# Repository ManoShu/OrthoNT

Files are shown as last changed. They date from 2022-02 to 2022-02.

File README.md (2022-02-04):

# OrthoNT

An open-source, QMK-compatible, (loosely) ABNT2-based 6x14 ortholinear keyboard.

---

Layout:

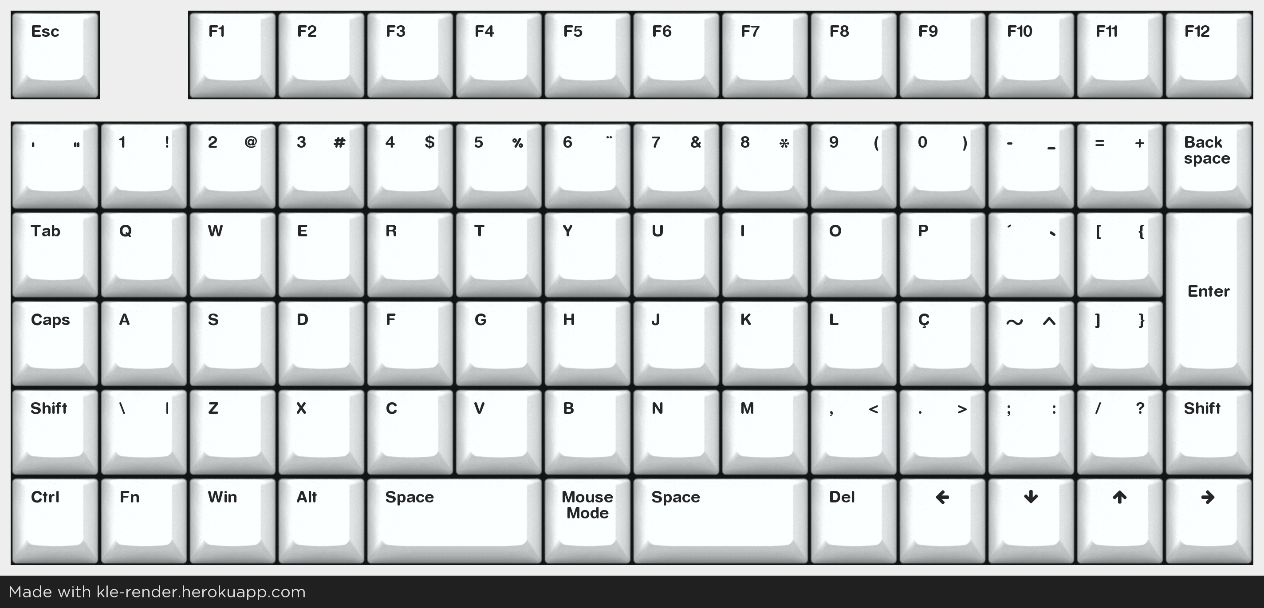
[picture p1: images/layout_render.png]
Keyboard Layout


Links: [KLE](http://www.keyboard-layout-editor.com/#/gists/c8b4991d1be04ef7142aadfa52a7956e), [JSON](https://gist.github.com/ManoShu/c8b4991d1be04ef7142aadfa52a7956e), [QMK](https://github.com/ManoShu/OrthoNT/tree/main/qmk/keyboards/handwired/orthont)

---

## PCB & Plate
The gerber files are under `production`. They had been used and confirmed to work, however use them at your own risk.

## QMK

No plan to integrate to the main QMK repository yet, as I am waiting for a proper VID/PID allocation. The files are on the `qmk` directory; just copy folder to qmk and it should work (HOWEVER the files have been confirmed working on QMK 0.2.2 [check yours with `qmk --version`], previous versions might not have support for some of the tags in the` info.json` file).

## VIA / VIAL

**NOTE: VIA / VIAL files have not been uploaded yet**

A `via` keymap is available allowing to use VIA to change keybindings withou the need to setup QMK. 
It is not integrated with the official repository yet (as I am waiting for a proper VID allocation), but the .json file required to change bindings is available on the `via` directory.

A VIAL-compatible keymap is also available. Drop the keyboard folder to your `vial-qmk` directory and it should also work right off the bat.

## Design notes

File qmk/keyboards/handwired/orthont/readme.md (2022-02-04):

# orthont

orthont

*A short description of the keyboard/project*

* Keyboard Maintainer: [ManoShu](https://github.com/yourusername)
* Hardware Supported: *The PCBs, controllers supported*
* Hardware Availability: *Links to where you can find this hardware*

Make example for this keyboard (after setting up your build environment):

    make orthont:default

Flashing example for this keyboard:

    make orthont:default:flash

See the [build environment setup](https://docs.qmk.fm/#/getting_started_build_tools) and the [make instructions](https://docs.qmk.fm/#/getting_started_make_guide) for more information. Brand new to QMK? Start with our [Complete Newbs Guide](https://docs.qmk.fm/#/newbs).

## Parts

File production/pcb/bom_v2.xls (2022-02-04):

Comment | Designator | Footprint | LCSC Part
0805W8F4700T5E | R7 | R_0805_2012Metric_Pad1.15x1.40mm_HandSolder | C17710
CC0805KRX7R9BB104 | C4,C5,C6 | C_0805_2012Metric_Pad1.15x1.40mm_HandSolder | C49678
0805W8F1000T5E | R8 | R_0805_2012Metric_Pad1.15x1.40mm_HandSolder | C17408
ATMEGA32U4-AU | U1 | TQFP-44_10x10mm_P0.8mm | C44854
USBLC6-2SC6 | U2 | SOT-23-6_Handsoldering | C2687116
1N4148W | D_R3C13,D_R5C13,D_R5C12,D_R5C11,D_R5C10,D_R5C9,D_R5C8,D_R5C6,D_R5C4,D_R5C3,D_R5C2,D_R5C1,D_R5C0,D_R4C13,D_R4C12,D_R4C11,D_R4C10,D_R4C9,D_R4C8,D_R4C7,D_R4C6,D_R4C5,D_R4C4,D_R4C3,D_R4C2,D_R4C1,D_R4C0,D_R3C12,D_R3C11,D_R3C10,D_R3C9,D_R3C8,D_R3C7,D_R3C6,D_R3C5,D_R3C4,D_R3C3,D_R3C2,D_R3C1,D_R3C0,D_R2C13,D_R2C12,D_R2C11,D_R2C10,D_R2C9,D_R2C8,D_R2C7,D_R2C6,D_R2C5,D_R2C4,D_R2C3,D_R2C2,D_R2C1,D_R2C0,D_R1C13,D_R1C12,D_R1C11,D_R1C10,D_R1C9,D_R1C8,D_R1C7,D_R1C6,D_R1C5,D_R1C4,D_R1C3,D_R1C2,D_R1C1,D_R1C0,D_R0C13,D_R0C12,D_R0C11,D_R0C10,D_R0C9,D_R0C8,D_R0C7,D_R0C6,D_R0C5,D_R0C4,D_R0C3,D_R0C2,D_R0C0 | D_SOD123_hand | C81598
0805W8F5101T5E | R6,R5 | R_0805_2012Metric_Pad1.15x1.40mm_HandSolder | C27834
CL21B105KBFNNNE | C8 | C_0805_2012Metric_Pad1.15x1.40mm_HandSolder | C28323
0805W8F1002T5E | R9,R1,R2 | R_0805_2012Metric_Pad1.15x1.40mm_HandSolder | C17414
TYPE-C-31-M-12 | USB1 | HRO-TYPE-C-31-M-12-HandSoldering | C165948
CL21A106KAYNNNE | C7 | C_0805_2012Metric_Pad1.15x1.40mm_HandSolder | C15850
TS-1187A-B-A-B | SW1 | SW_SPST_SKQG_WithStem | C318884
JK-NSMD050-13.2V | F1 | Fuse_1206_3216Metric_Pad1.42x1.75mm_HandSolder | C369159
0805W8F220JT5E | R3,R4 | R_0805_2012Metric_Pad1.15x1.40mm_HandSolder | C17561
X322516MLB4SI | X1 | Crystal_SMD_3225-4Pin_3.2x2.5mm_HandSoldering | C13738
AO3401A | Q1 | SOT-23_Handsoldering | C15127
CL21C220JBANNNC | C1,C2 | C_0805_2012Metric_Pad1.15x1.40mm_HandSolder | C1804
0805W8F2001T5E | R_R4C7,R_R5C13,R_R5C12,R_R5C11,R_R5C10,R_R5C9,R_R5C8,R_R5C6,R_R5C4,R_R5C3,R_R5C2,R_R5C1,R_R5C0,R_R4C13,R_R4C12,R_R4C11,R_R4C10,R_R4C9,R_R4C8,R_R4C6,R_R4C5,R_R4C4,R_R4C3,R_R4C2,R_R4C1,R_R4C0,R_R3C12,R_R3C11,R_R3C10,R_R3C9,R_R3C8,R_R3C7,R_R3C6,R_R3C5,R_R3C4,R_R3C3,R_R3C2,R_R3C1,R_R3C0,R_R2C13,R_R2C12,R_R2C11,R_R2C10,R_R2C9,R_R2C8,R_R2C7,R_R2C6,R_R2C5,R_R2C4,R_R2C3,R_R2C2,R_R2C1,R_R2C0,R_R1C13,R_R1C12,R_R1C11,R_R1C10,R_R1C9,R_R1C8,R_R1C7,R_R1C6,R_R1C5,R_R1C4,R_R1C3,R_R1C2,R_R1C1,R_R1C0,R_R0C13,R_R0C12,R_R0C11,R_R0C10,R_R0C9,R_R0C8,R_R0C7,R_R0C6,R_R0C5,R_R0C4,R_R0C3,R_R0C2,R_R0C0 | R_0805_2012Metric_Pad1.15x1.40mm_HandSolder | C17604
C2290 | D1 | LED_0603_1608Metric_Pad1.05x0.95mm_HandSolder | C2290
SM04B-SRSS-TB(LF)(SN) | J1 | JST_SH_SM04B-SRSS-TB_1x04-1MP_P1.00mm_Horizontal | C160404

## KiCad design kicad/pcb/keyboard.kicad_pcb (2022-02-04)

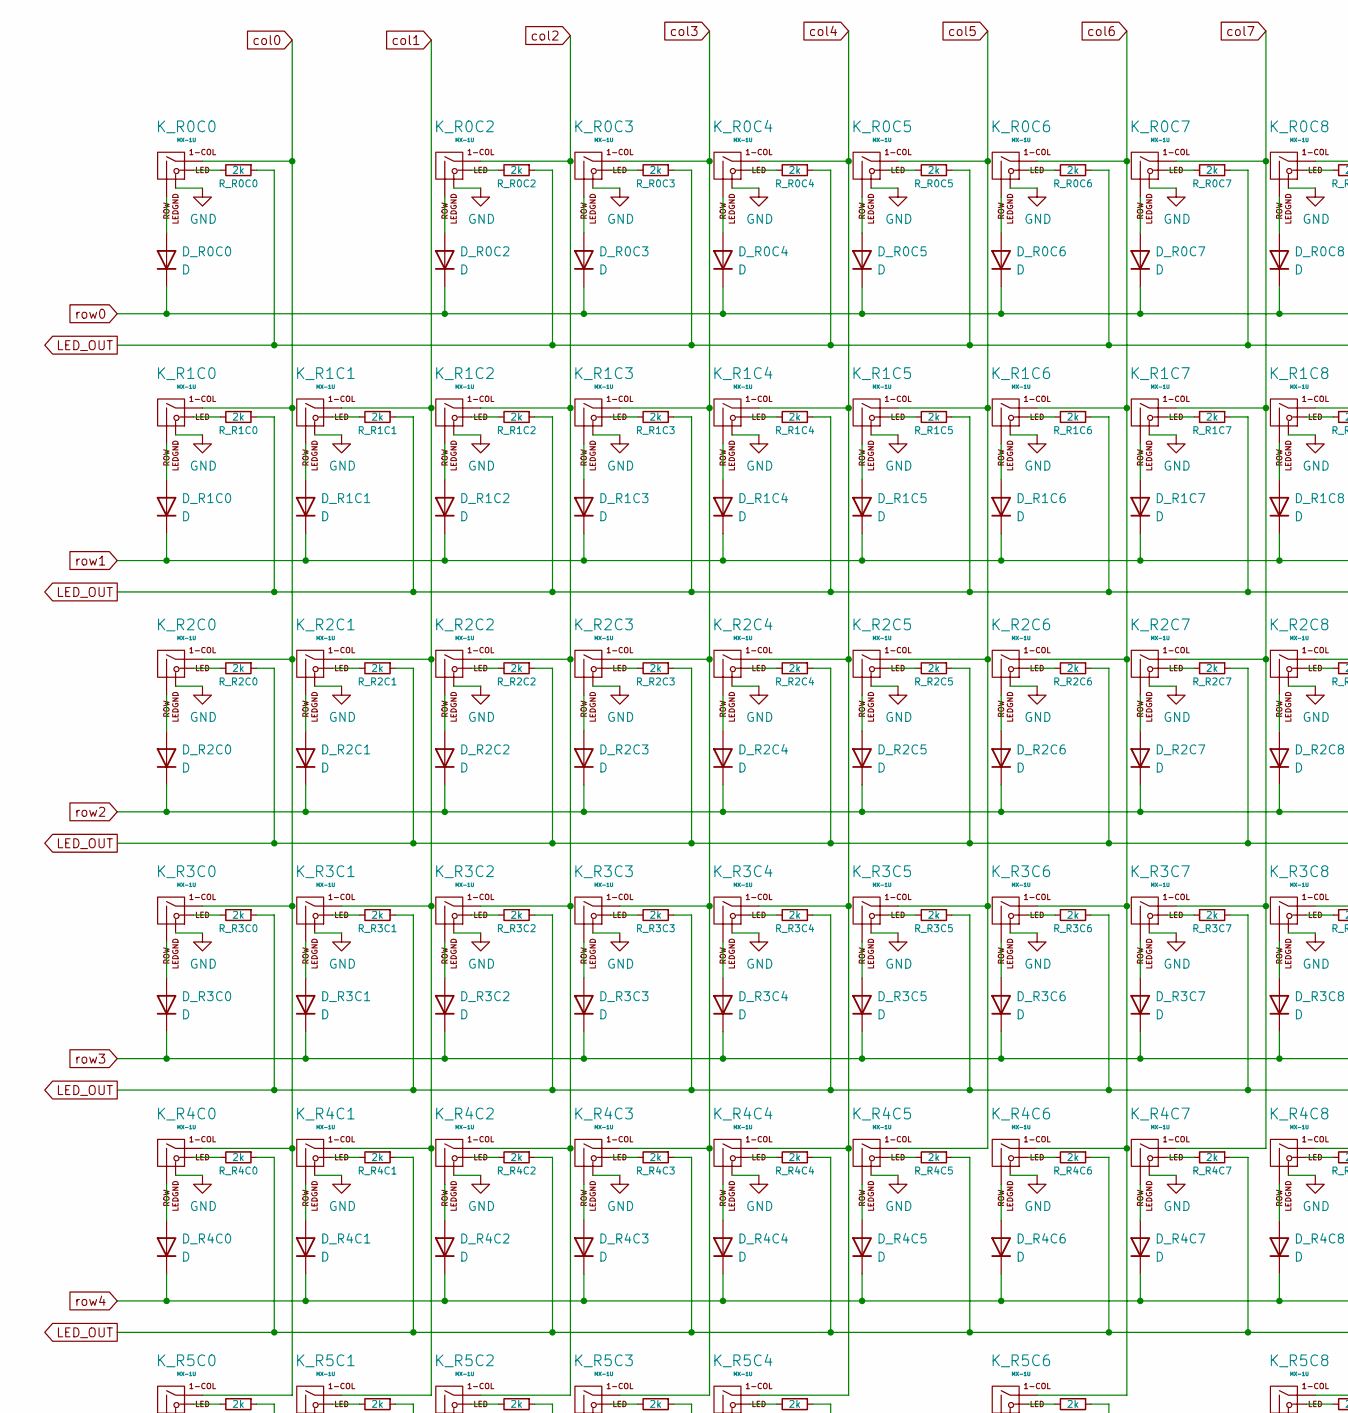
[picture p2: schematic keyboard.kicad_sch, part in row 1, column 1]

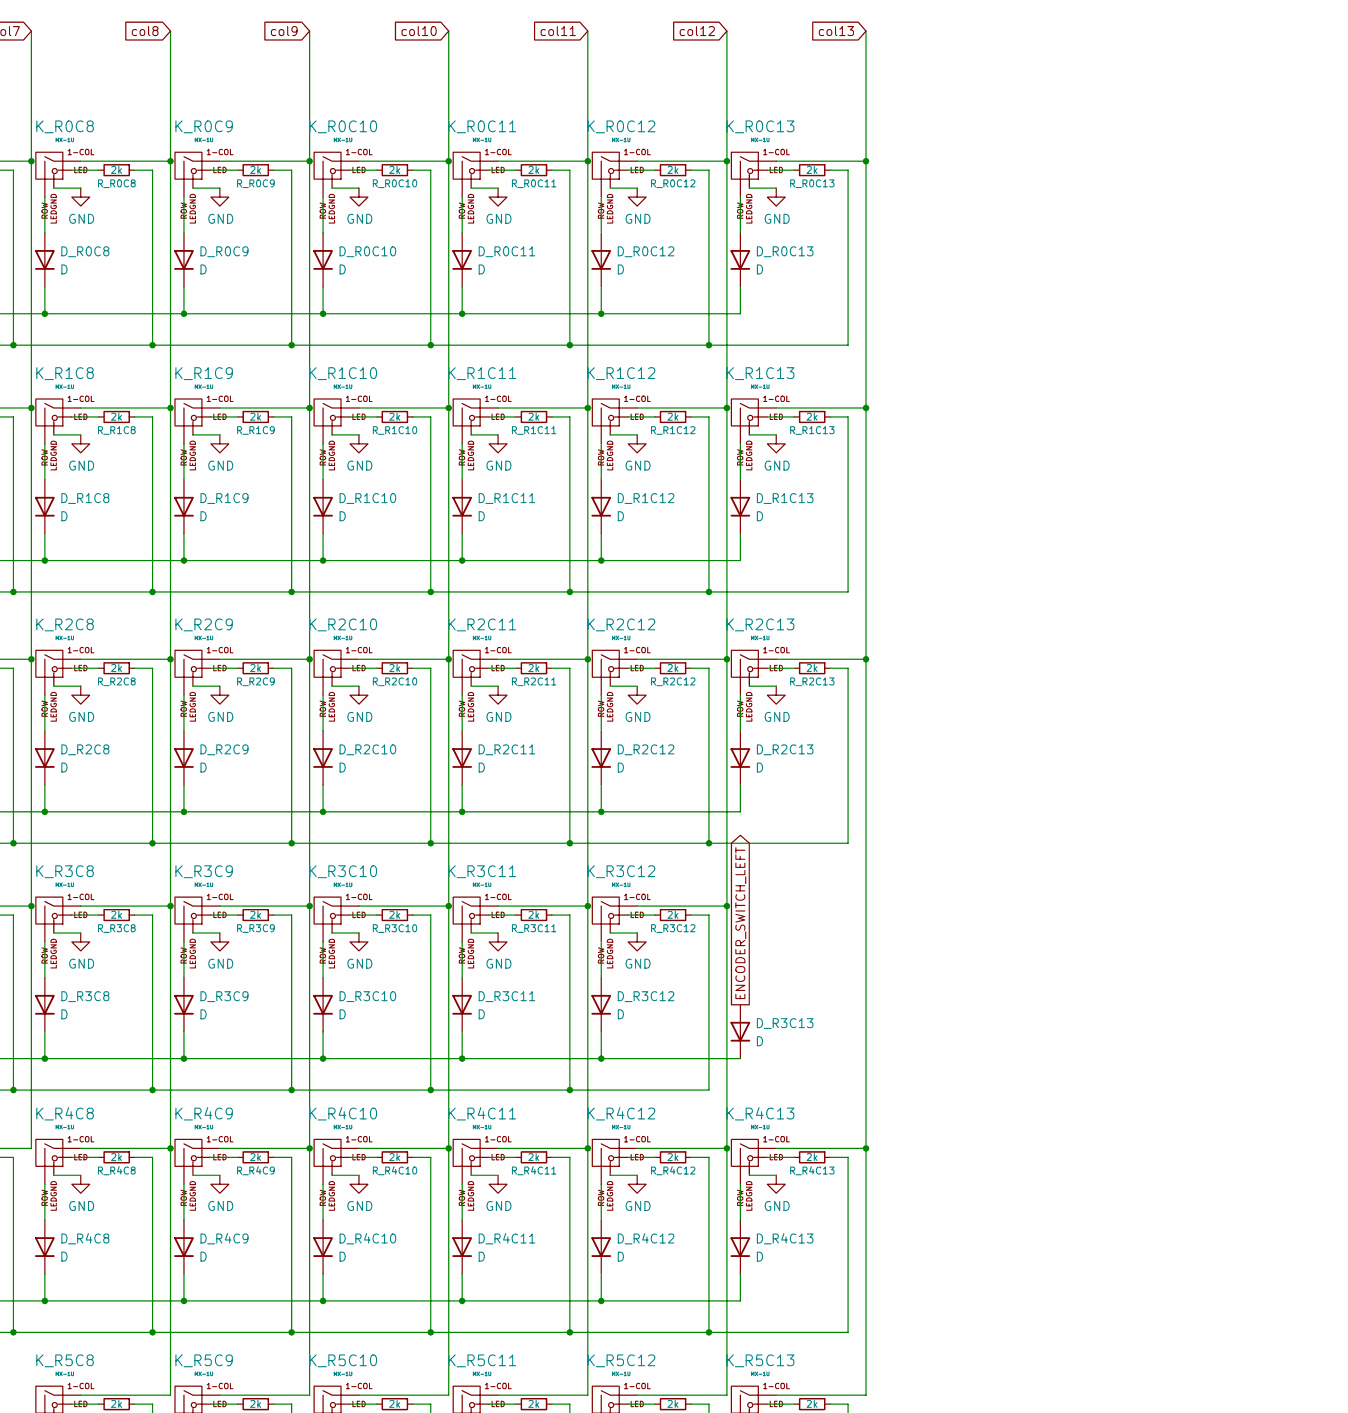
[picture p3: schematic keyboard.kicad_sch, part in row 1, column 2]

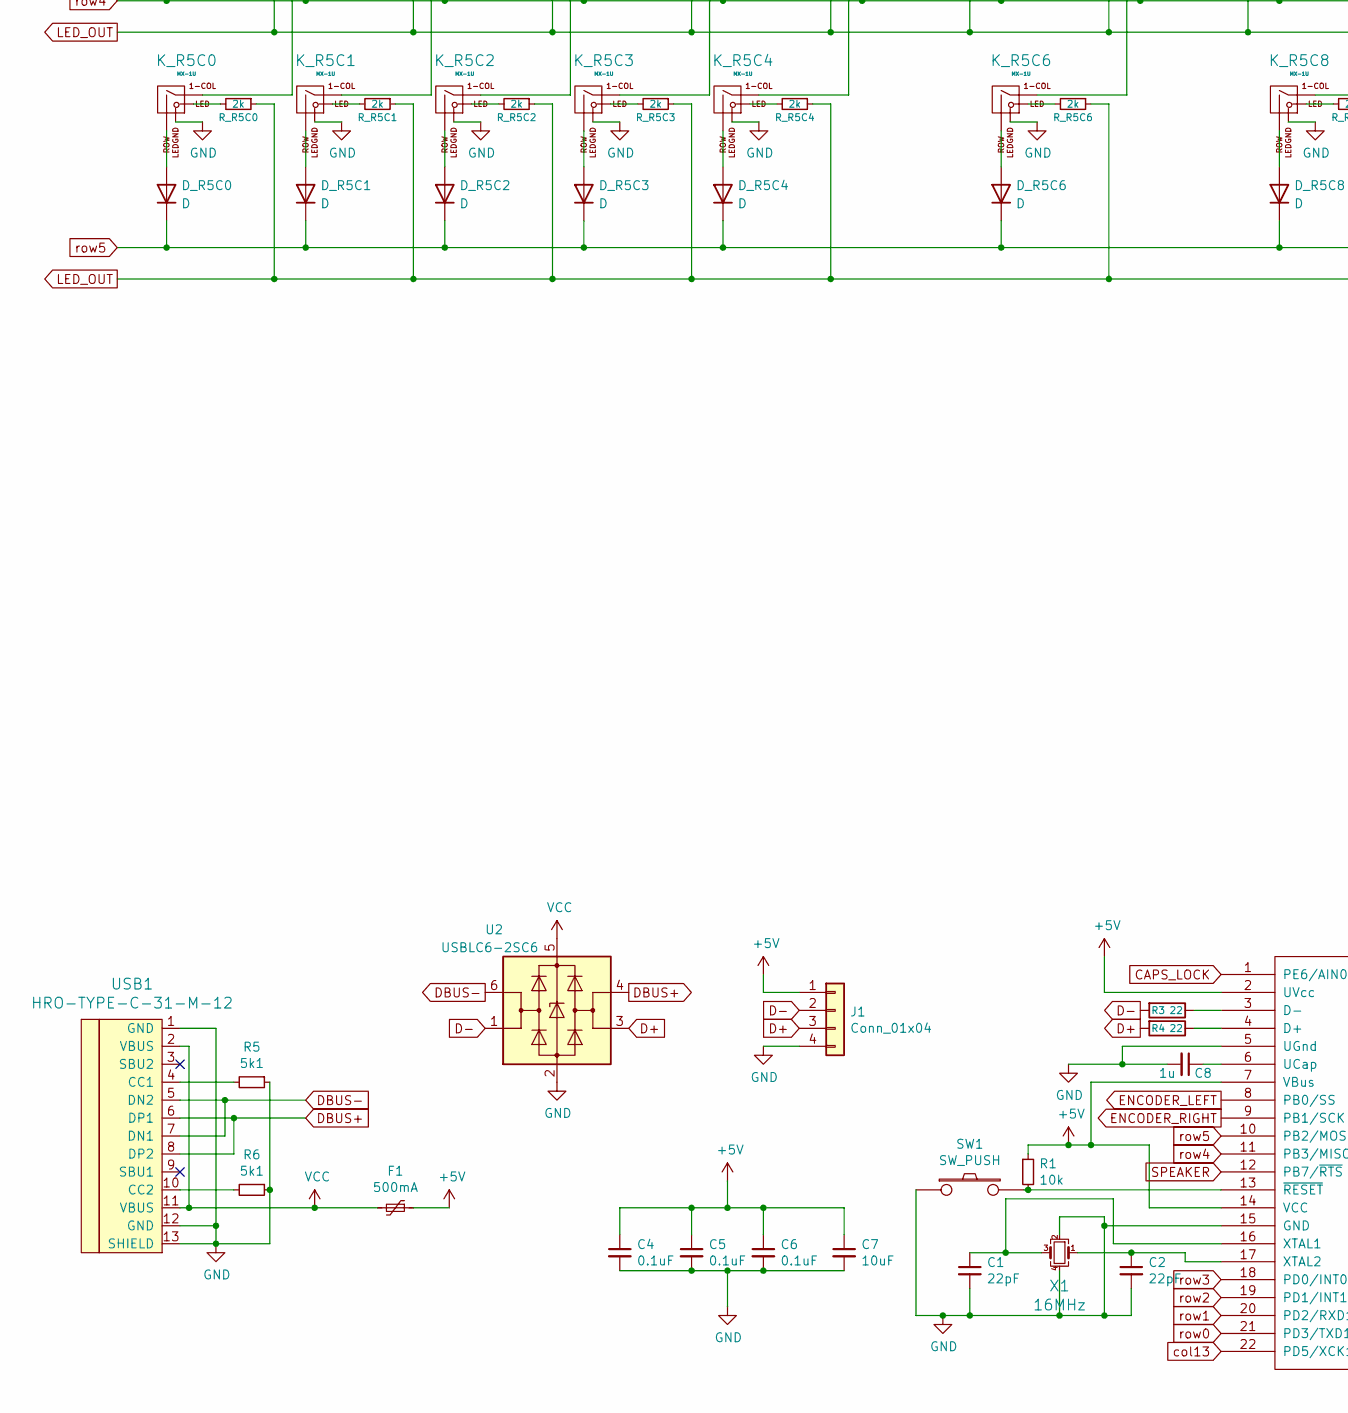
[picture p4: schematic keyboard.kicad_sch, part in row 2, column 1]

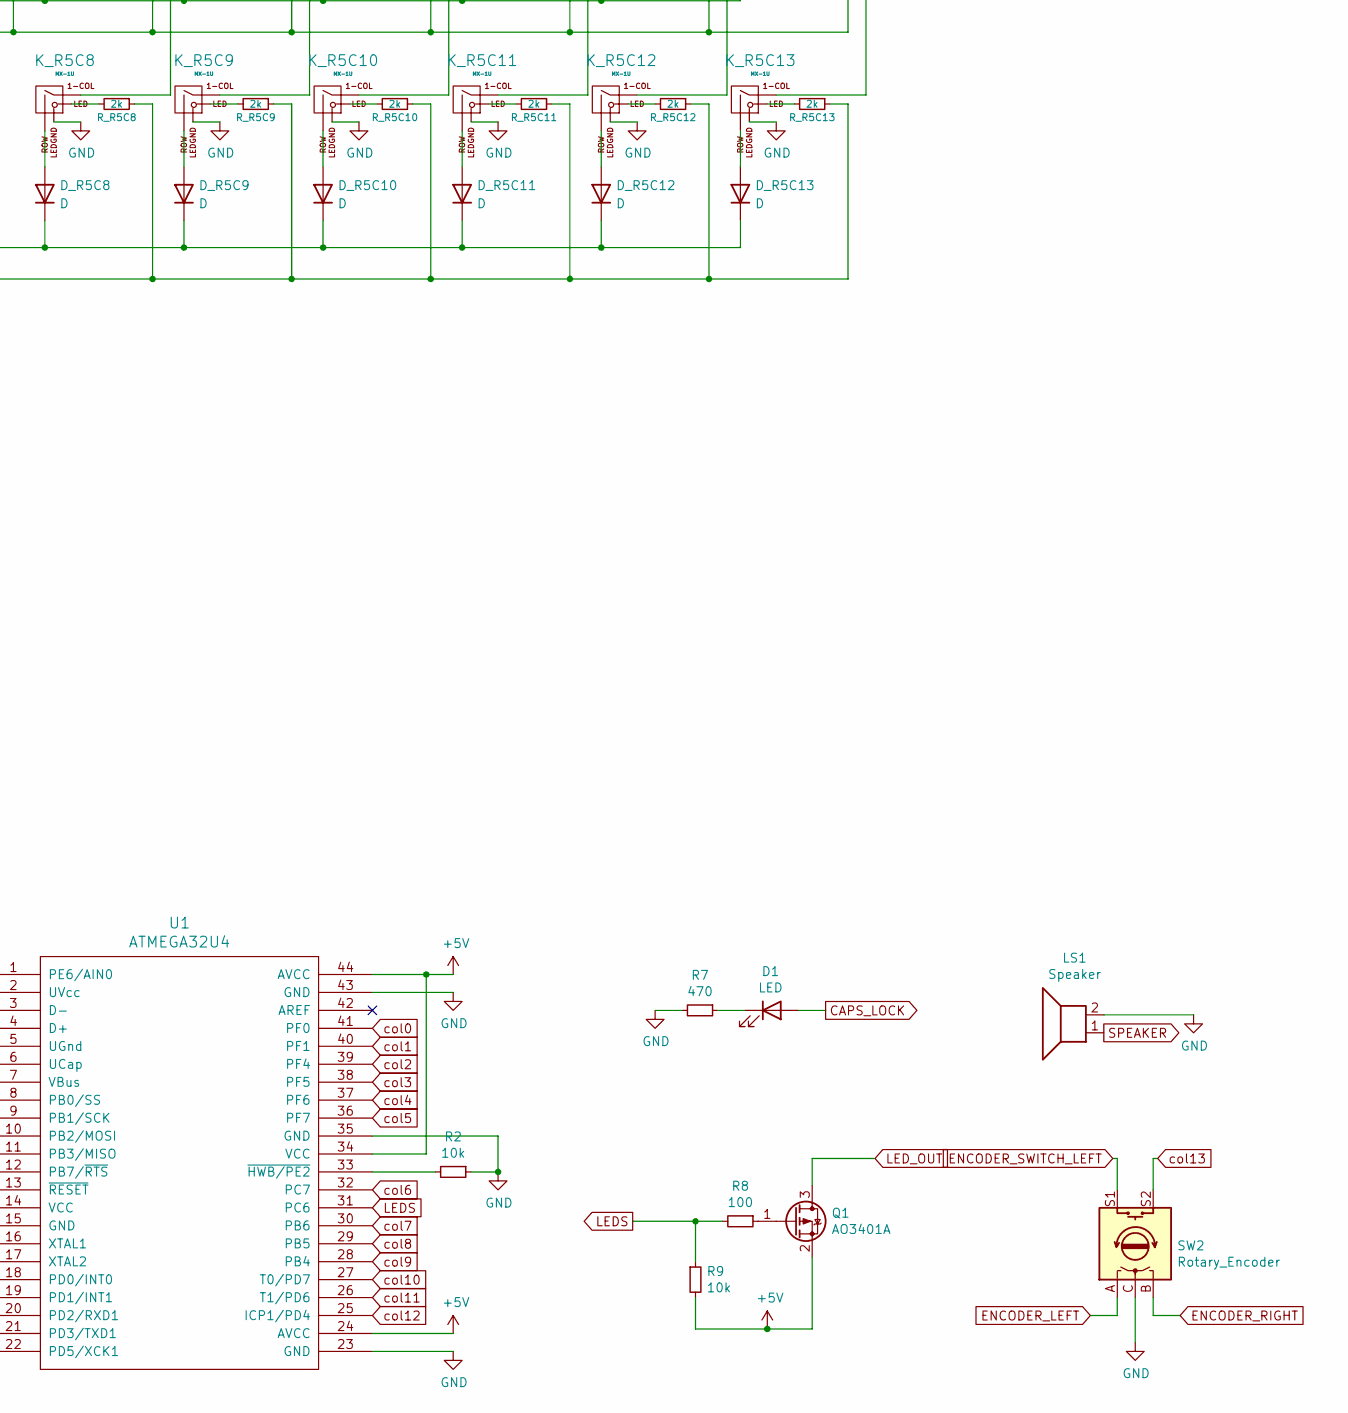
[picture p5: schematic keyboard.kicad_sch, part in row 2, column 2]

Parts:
C1, C2: 22pF; C_0805_2012Metric_Pad1.15x1.40mm_HandSolder
C4, C5, C6: 0.1uF; C_0805_2012Metric_Pad1.15x1.40mm_HandSolder
C7: 10uF; C_0805_2012Metric_Pad1.15x1.40mm_HandSolder
C8: 1u; C_0805_2012Metric_Pad1.15x1.40mm_HandSolder
D1: LED; LED_0603_1608Metric_Pad1.05x0.95mm_HandSolder
D_R0C0, D_R0C2, D_R0C3, D_R0C4, D_R0C5, D_R0C6, D_R0C7, D_R0C8, D_R0C9, D_R0C10, D_R0C11, D_R0C12, D_R0C13, D_R1C0, D_R1C1, D_R1C2, D_R1C3, D_R1C4, D_R1C5, D_R1C6, D_R1C7, D_R1C8, D_R1C9, D_R1C10, D_R1C11, D_R1C12, D_R1C13, D_R2C0, D_R2C1, D_R2C2, D_R2C3, D_R2C4, D_R2C5, D_R2C6, D_R2C7, D_R2C8, D_R2C9, D_R2C10, D_R2C11, D_R2C12, D_R2C13, D_R3C0, D_R3C1, D_R3C2, D_R3C3, D_R3C4, D_R3C5, D_R3C6, D_R3C7, D_R3C8, D_R3C9, D_R3C10, D_R3C11, D_R3C12, D_R3C13, D_R4C0, D_R4C1, D_R4C2, D_R4C3, D_R4C4, D_R4C5, D_R4C6, D_R4C7, D_R4C8, D_R4C9, D_R4C10, D_R4C11, D_R4C12, D_R4C13, D_R5C0, D_R5C1, D_R5C2, D_R5C3, D_R5C4, D_R5C6, D_R5C8, D_R5C9, D_R5C10, D_R5C11, D_R5C12, D_R5C13: D; D_SOD123_hand
F1: 500mA; Fuse_1206_3216Metric_Pad1.42x1.75mm_HandSolder
J1: Conn_01x04; JST_SH_SM04B-SRSS-TB_1x04-1MP_P1.00mm_Horizontal
K_R0C0, K_R0C2, K_R0C3, K_R0C4, K_R0C5, K_R0C6, K_R0C7, K_R0C8, K_R0C9, K_R0C10, K_R0C11, K_R0C12, K_R0C13, K_R1C0, K_R1C1, K_R1C2, K_R1C3, K_R1C4, K_R1C5, K_R1C6, K_R1C7, K_R1C8, K_R1C9, K_R1C10, K_R1C11, K_R1C12, K_R1C13, K_R2C0, K_R2C1, K_R2C2, K_R2C3, K_R2C4, K_R2C5, K_R2C6, K_R2C7, K_R2C8, K_R2C9, K_R2C10, K_R2C11, K_R2C12, K_R3C0, K_R3C1, K_R3C2, K_R3C3, K_R3C4, K_R3C5, K_R3C6, K_R3C7, K_R3C8, K_R3C9, K_R3C10, K_R3C11, K_R3C12, K_R4C0, K_R4C1, K_R4C2, K_R4C3, K_R4C4, K_R4C5, K_R4C6, K_R4C7, K_R4C8, K_R4C9, K_R4C10, K_R4C11, K_R4C12, K_R4C13, K_R5C0, K_R5C1, K_R5C2, K_R5C3, K_R5C6, K_R5C9, K_R5C10, K_R5C11, K_R5C12, K_R5C13: MX-1U; MXOnly-1U
K_R2C13: MX-1U; MXOnly-2U_RightAngle
K_R5C4, K_R5C8: MX-1U; MXOnly-2U
LS1: Speaker; PinHeader_1x02_P2.54mm_Horizontal
Q1: AO3401A; SOT-23_Handsoldering
R1, R2, R9: 10k; R_0805_2012Metric_Pad1.15x1.40mm_HandSolder
R3, R4: 22; R_0805_2012Metric_Pad1.15x1.40mm_HandSolder
R5, R6: 5k1; R_0805_2012Metric_Pad1.15x1.40mm_HandSolder
R7: 470; R_0805_2012Metric_Pad1.15x1.40mm_HandSolder
R8: 100; R_0805_2012Metric_Pad1.15x1.40mm_HandSolder
R_R0C0, R_R0C2, R_R0C3, R_R0C4, R_R0C5, R_R0C6, R_R0C7, R_R0C8, R_R0C9, R_R0C10, R_R0C11, R_R0C12, R_R0C13, R_R1C0, R_R1C1, R_R1C2, R_R1C3, R_R1C4, R_R1C5, R_R1C6, R_R1C7, R_R1C8, R_R1C9, R_R1C10, R_R1C11, R_R1C12, R_R1C13, R_R2C0, R_R2C1, R_R2C2, R_R2C3, R_R2C4, R_R2C5, R_R2C6, R_R2C7, R_R2C8, R_R2C9, R_R2C10, R_R2C11, R_R2C12, R_R2C13, R_R3C0, R_R3C1, R_R3C2, R_R3C3, R_R3C4, R_R3C5, R_R3C6, R_R3C7, R_R3C8, R_R3C9, R_R3C10, R_R3C11, R_R3C12, R_R4C0, R_R4C1, R_R4C2, R_R4C3, R_R4C4, R_R4C5, R_R4C6, R_R4C7, R_R4C8, R_R4C9, R_R4C10, R_R4C11, R_R4C12, R_R4C13, R_R5C0, R_R5C1, R_R5C2, R_R5C3, R_R5C4, R_R5C6, R_R5C8, R_R5C9, R_R5C10, R_R5C11, R_R5C12, R_R5C13: 2k; R_0805_2012Metric_Pad1.15x1.40mm_HandSolder
SW1: SW_PUSH; SW_SPST_SKQG_WithStem
SW2: Rotary_Encoder; RotaryEncoder_Alps_EC11E-Switch_Vertical_H20mm
U1: ATMEGA32U4; TQFP-44_10x10mm_P0.8mm
U2: USBLC6-2SC6; SOT-23-6_Handsoldering
USB1: HRO-TYPE-C-31-M-12; HRO-TYPE-C-31-M-12-HandSoldering
X1: 16MHz; Crystal_SMD_3225-4Pin_3.2x2.5mm_HandSoldering

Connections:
+5V: C4.1, C5.1, C6.1, C7.1, F1.1, J1.1, Q1.2 (S), R1.1, R9.2, U1.2 (UVcc), U1.7 (VBus), U1.14 (VCC), U1.24 (AVCC), U1.34 (VCC), U1.44 (AVCC)
CAPS_LOCK: D1.2 (A), U1.1 (PE6/AIN0)
D+: J1.3, R4.2, U2.3 (I/O2)
D-: J1.2, R3.2, U2.1 (I/O1)
DBUS+: U2.4 (I/O2), USB1.6 (DP1), USB1.8 (DP2)
DBUS-: U2.6 (I/O1), USB1.5 (DN2), USB1.7 (DN1)
ENCODER_LEFT: SW2.A, U1.8 (PB0/SS)
ENCODER_RIGHT: SW2.B, U1.9 (PB1/SCK)
ENCODER_SWITCH_LEFT: D_R3C13.2 (A), SW2.S1
GND: C1.2, C2.2, C4.2, C5.2, C6.2, C7.2, C8.2, J1.4, K_R0C0.4 (LEDGND), K_R0C2.4 (LEDGND), K_R0C3.4 (LEDGND), K_R0C4.4 (LEDGND), K_R0C5.4 (LEDGND), K_R0C6.4 (LEDGND), K_R0C7.4 (LEDGND), K_R0C8.4 (LEDGND), K_R0C9.4 (LEDGND), K_R0C10.4 (LEDGND), K_R0C11.4 (LEDGND), K_R0C12.4 (LEDGND), K_R0C13.4 (LEDGND), K_R1C0.4 (LEDGND), K_R1C1.4 (LEDGND), K_R1C2.4 (LEDGND), K_R1C3.4 (LEDGND), K_R1C4.4 (LEDGND), K_R1C5.4 (LEDGND), K_R1C6.4 (LEDGND), K_R1C7.4 (LEDGND), K_R1C8.4 (LEDGND), K_R1C9.4 (LEDGND), K_R1C10.4 (LEDGND), K_R1C11.4 (LEDGND), K_R1C12.4 (LEDGND), K_R1C13.4 (LEDGND), K_R2C0.4 (LEDGND), K_R2C1.4 (LEDGND), K_R2C2.4 (LEDGND), K_R2C3.4 (LEDGND), K_R2C4.4 (LEDGND), K_R2C5.4 (LEDGND), K_R2C6.4 (LEDGND), K_R2C7.4 (LEDGND), K_R2C8.4 (LEDGND), K_R2C9.4 (LEDGND), K_R2C10.4 (LEDGND), K_R2C11.4 (LEDGND), K_R2C12.4 (LEDGND), K_R2C13.4 (LEDGND), K_R3C0.4 (LEDGND), K_R3C1.4 (LEDGND), K_R3C2.4 (LEDGND), K_R3C3.4 (LEDGND), K_R3C4.4 (LEDGND), K_R3C5.4 (LEDGND), K_R3C6.4 (LEDGND), K_R3C7.4 (LEDGND), K_R3C8.4 (LEDGND), K_R3C9.4 (LEDGND), K_R3C10.4 (LEDGND), K_R3C11.4 (LEDGND), K_R3C12.4 (LEDGND), K_R4C0.4 (LEDGND), K_R4C1.4 (LEDGND), K_R4C2.4 (LEDGND), K_R4C3.4 (LEDGND), K_R4C4.4 (LEDGND), K_R4C5.4 (LEDGND), K_R4C6.4 (LEDGND), K_R4C7.4 (LEDGND), K_R4C8.4 (LEDGND), K_R4C9.4 (LEDGND), K_R4C10.4 (LEDGND), K_R4C11.4 (LEDGND), K_R4C12.4 (LEDGND), K_R4C13.4 (LEDGND), K_R5C0.4 (LEDGND), K_R5C1.4 (LEDGND), K_R5C2.4 (LEDGND), K_R5C3.4 (LEDGND), K_R5C4.4 (LEDGND), K_R5C6.4 (LEDGND), K_R5C8.4 (LEDGND), K_R5C9.4 (LEDGND), K_R5C10.4 (LEDGND), K_R5C11.4 (LEDGND), K_R5C12.4 (LEDGND), K_R5C13.4 (LEDGND), LS1.2, R2.1, R5.1, R6.1, R7.2, SW1.1, SW2.C, U1.5 (UGnd), U1.15 (GND), U1.23 (GND), U1.35 (GND), U1.43 (GND), U2.2 (GND), USB1.1 (GND), USB1.12 (GND), USB1.13 (SHIELD), X1.2, X1.4
LEDS: R8.2, R9.1, U1.31 (PC6)
LED_OUT: Q1.3 (D), R_R0C0.1, R_R0C2.1, R_R0C3.1, R_R0C4.1, R_R0C5.1, R_R0C6.1, R_R0C7.1, R_R0C8.1, R_R0C9.1, R_R0C10.1, R_R0C11.1, R_R0C12.1, R_R0C13.1, R_R1C0.1, R_R1C1.1, R_R1C2.1, R_R1C3.1, R_R1C4.1, R_R1C5.1, R_R1C6.1, R_R1C7.1, R_R1C8.1, R_R1C9.1, R_R1C10.1, R_R1C11.1, R_R1C12.1, R_R1C13.1, R_R2C0.1, R_R2C1.1, R_R2C2.1, R_R2C3.1, R_R2C4.1, R_R2C5.1, R_R2C6.1, R_R2C7.1, R_R2C8.1, R_R2C9.1, R_R2C10.1, R_R2C11.1, R_R2C12.1, R_R2C13.1, R_R3C0.1, R_R3C1.1, R_R3C2.1, R_R3C3.1, R_R3C4.1, R_R3C5.1, R_R3C6.1, R_R3C7.1, R_R3C8.1, R_R3C9.1, R_R3C10.1, R_R3C11.1, R_R3C12.1, R_R4C0.1, R_R4C1.1, R_R4C2.1, R_R4C3.1, R_R4C4.1, R_R4C5.1, R_R4C6.1, R_R4C7.1, R_R4C8.1, R_R4C9.1, R_R4C10.1, R_R4C11.1, R_R4C12.1, R_R4C13.1, R_R5C0.1, R_R5C1.1, R_R5C2.1, R_R5C3.1, R_R5C4.1, R_R5C6.1, R_R5C8.1, R_R5C9.1, R_R5C10.1, R_R5C11.1, R_R5C12.1, R_R5C13.1
unnamed: C1.1, U1.16 (XTAL1), X1.3
unnamed: C2.1, U1.17 (XTAL2), X1.1
unnamed: C8.1, U1.6 (UCap)
unnamed: D1.1 (K), R7.1
unnamed: D_R0C0.2 (A), K_R0C0.2 (ROW)
unnamed: D_R0C2.2 (A), K_R0C2.2 (ROW)
unnamed: D_R0C3.2 (A), K_R0C3.2 (ROW)
unnamed: D_R0C4.2 (A), K_R0C4.2 (ROW)
unnamed: D_R0C5.2 (A), K_R0C5.2 (ROW)
unnamed: D_R0C6.2 (A), K_R0C6.2 (ROW)
unnamed: D_R0C7.2 (A), K_R0C7.2 (ROW)
unnamed: D_R0C8.2 (A), K_R0C8.2 (ROW)
unnamed: D_R0C9.2 (A), K_R0C9.2 (ROW)
unnamed: D_R0C10.2 (A), K_R0C10.2 (ROW)
unnamed: D_R0C11.2 (A), K_R0C11.2 (ROW)
unnamed: D_R0C12.2 (A), K_R0C12.2 (ROW)
unnamed: D_R0C13.2 (A), K_R0C13.2 (ROW)
unnamed: D_R1C0.2 (A), K_R1C0.2 (ROW)
unnamed: D_R1C1.2 (A), K_R1C1.2 (ROW)
unnamed: D_R1C2.2 (A), K_R1C2.2 (ROW)
unnamed: D_R1C3.2 (A), K_R1C3.2 (ROW)
unnamed: D_R1C4.2 (A), K_R1C4.2 (ROW)
unnamed: D_R1C5.2 (A), K_R1C5.2 (ROW)
unnamed: D_R1C6.2 (A), K_R1C6.2 (ROW)
unnamed: D_R1C7.2 (A), K_R1C7.2 (ROW)
unnamed: D_R1C8.2 (A), K_R1C8.2 (ROW)
unnamed: D_R1C9.2 (A), K_R1C9.2 (ROW)
unnamed: D_R1C10.2 (A), K_R1C10.2 (ROW)
unnamed: D_R1C11.2 (A), K_R1C11.2 (ROW)
unnamed: D_R1C12.2 (A), K_R1C12.2 (ROW)
unnamed: D_R1C13.2 (A), K_R1C13.2 (ROW)
unnamed: D_R2C0.2 (A), K_R2C0.2 (ROW)
unnamed: D_R2C1.2 (A), K_R2C1.2 (ROW)
unnamed: D_R2C2.2 (A), K_R2C2.2 (ROW)
unnamed: D_R2C3.2 (A), K_R2C3.2 (ROW)
unnamed: D_R2C4.2 (A), K_R2C4.2 (ROW)
unnamed: D_R2C5.2 (A), K_R2C5.2 (ROW)
unnamed: D_R2C6.2 (A), K_R2C6.2 (ROW)
unnamed: D_R2C7.2 (A), K_R2C7.2 (ROW)
unnamed: D_R2C8.2 (A), K_R2C8.2 (ROW)
unnamed: D_R2C9.2 (A), K_R2C9.2 (ROW)
unnamed: D_R2C10.2 (A), K_R2C10.2 (ROW)
unnamed: D_R2C11.2 (A), K_R2C11.2 (ROW)
unnamed: D_R2C12.2 (A), K_R2C12.2 (ROW)
unnamed: D_R2C13.2 (A), K_R2C13.2 (ROW)
unnamed: D_R3C0.2 (A), K_R3C0.2 (ROW)
unnamed: D_R3C1.2 (A), K_R3C1.2 (ROW)
unnamed: D_R3C2.2 (A), K_R3C2.2 (ROW)
unnamed: D_R3C3.2 (A), K_R3C3.2 (ROW)
unnamed: D_R3C4.2 (A), K_R3C4.2 (ROW)
unnamed: D_R3C5.2 (A), K_R3C5.2 (ROW)
unnamed: D_R3C6.2 (A), K_R3C6.2 (ROW)
unnamed: D_R3C7.2 (A), K_R3C7.2 (ROW)
unnamed: D_R3C8.2 (A), K_R3C8.2 (ROW)
unnamed: D_R3C9.2 (A), K_R3C9.2 (ROW)
unnamed: D_R3C10.2 (A), K_R3C10.2 (ROW)
unnamed: D_R3C11.2 (A), K_R3C11.2 (ROW)
unnamed: D_R3C12.2 (A), K_R3C12.2 (ROW)
unnamed: D_R4C0.2 (A), K_R4C0.2 (ROW)
unnamed: D_R4C1.2 (A), K_R4C1.2 (ROW)
unnamed: D_R4C2.2 (A), K_R4C2.2 (ROW)
unnamed: D_R4C3.2 (A), K_R4C3.2 (ROW)
unnamed: D_R4C4.2 (A), K_R4C4.2 (ROW)
unnamed: D_R4C5.2 (A), K_R4C5.2 (ROW)
unnamed: D_R4C6.2 (A), K_R4C6.2 (ROW)
unnamed: D_R4C7.2 (A), K_R4C7.2 (ROW)
unnamed: D_R4C8.2 (A), K_R4C8.2 (ROW)
unnamed: D_R4C9.2 (A), K_R4C9.2 (ROW)
unnamed: D_R4C10.2 (A), K_R4C10.2 (ROW)
unnamed: D_R4C11.2 (A), K_R4C11.2 (ROW)
unnamed: D_R4C12.2 (A), K_R4C12.2 (ROW)
unnamed: D_R4C13.2 (A), K_R4C13.2 (ROW)
unnamed: D_R5C0.2 (A), K_R5C0.2 (ROW)
unnamed: D_R5C1.2 (A), K_R5C1.2 (ROW)
unnamed: D_R5C2.2 (A), K_R5C2.2 (ROW)
unnamed: D_R5C3.2 (A), K_R5C3.2 (ROW)
unnamed: D_R5C4.2 (A), K_R5C4.2 (ROW)
unnamed: D_R5C6.2 (A), K_R5C6.2 (ROW)
unnamed: D_R5C8.2 (A), K_R5C8.2 (ROW)
unnamed: D_R5C9.2 (A), K_R5C9.2 (ROW)
unnamed: D_R5C10.2 (A), K_R5C10.2 (ROW)
unnamed: D_R5C11.2 (A), K_R5C11.2 (ROW)
unnamed: D_R5C12.2 (A), K_R5C12.2 (ROW)
unnamed: D_R5C13.2 (A), K_R5C13.2 (ROW)
unnamed: K_R0C0.3 (LED), R_R0C0.2
unnamed: K_R0C2.3 (LED), R_R0C2.2
unnamed: K_R0C3.3 (LED), R_R0C3.2
unnamed: K_R0C4.3 (LED), R_R0C4.2
unnamed: K_R0C5.3 (LED), R_R0C5.2
unnamed: K_R0C6.3 (LED), R_R0C6.2
unnamed: K_R0C7.3 (LED), R_R0C7.2
unnamed: K_R0C8.3 (LED), R_R0C8.2
unnamed: K_R0C9.3 (LED), R_R0C9.2
unnamed: K_R0C10.3 (LED), R_R0C10.2
unnamed: K_R0C11.3 (LED), R_R0C11.2
unnamed: K_R0C12.3 (LED), R_R0C12.2
unnamed: K_R0C13.3 (LED), R_R0C13.2
unnamed: K_R1C0.3 (LED), R_R1C0.2
unnamed: K_R1C1.3 (LED), R_R1C1.2
unnamed: K_R1C2.3 (LED), R_R1C2.2
unnamed: K_R1C3.3 (LED), R_R1C3.2
unnamed: K_R1C4.3 (LED), R_R1C4.2
unnamed: K_R1C5.3 (LED), R_R1C5.2
unnamed: K_R1C6.3 (LED), R_R1C6.2
unnamed: K_R1C7.3 (LED), R_R1C7.2
unnamed: K_R1C8.3 (LED), R_R1C8.2
unnamed: K_R1C9.3 (LED), R_R1C9.2
unnamed: K_R1C10.3 (LED), R_R1C10.2
unnamed: K_R1C11.3 (LED), R_R1C11.2
unnamed: K_R1C12.3 (LED), R_R1C12.2
unnamed: K_R1C13.3 (LED), R_R1C13.2
unnamed: K_R2C0.3 (LED), R_R2C0.2
unnamed: K_R2C1.3 (LED), R_R2C1.2
unnamed: K_R2C2.3 (LED), R_R2C2.2
unnamed: K_R2C3.3 (LED), R_R2C3.2
unnamed: K_R2C4.3 (LED), R_R2C4.2
unnamed: K_R2C5.3 (LED), R_R2C5.2
unnamed: K_R2C6.3 (LED), R_R2C6.2
unnamed: K_R2C7.3 (LED), R_R2C7.2
unnamed: K_R2C8.3 (LED), R_R2C8.2
unnamed: K_R2C9.3 (LED), R_R2C9.2
unnamed: K_R2C10.3 (LED), R_R2C10.2
unnamed: K_R2C11.3 (LED), R_R2C11.2
unnamed: K_R2C12.3 (LED), R_R2C12.2
unnamed: K_R2C13.3 (LED), R_R2C13.2
unnamed: K_R3C0.3 (LED), R_R3C0.2
unnamed: K_R3C1.3 (LED), R_R3C1.2
unnamed: K_R3C2.3 (LED), R_R3C2.2
unnamed: K_R3C3.3 (LED), R_R3C3.2
unnamed: K_R3C4.3 (LED), R_R3C4.2
unnamed: K_R3C5.3 (LED), R_R3C5.2
unnamed: K_R3C6.3 (LED), R_R3C6.2
unnamed: K_R3C7.3 (LED), R_R3C7.2
unnamed: K_R3C8.3 (LED), R_R3C8.2
unnamed: K_R3C9.3 (LED), R_R3C9.2
unnamed: K_R3C10.3 (LED), R_R3C10.2
unnamed: K_R3C11.3 (LED), R_R3C11.2
unnamed: K_R3C12.3 (LED), R_R3C12.2
unnamed: K_R4C0.3 (LED), R_R4C0.2
unnamed: K_R4C1.3 (LED), R_R4C1.2
unnamed: K_R4C2.3 (LED), R_R4C2.2
unnamed: K_R4C3.3 (LED), R_R4C3.2
unnamed: K_R4C4.3 (LED), R_R4C4.2
unnamed: K_R4C5.3 (LED), R_R4C5.2
unnamed: K_R4C6.3 (LED), R_R4C6.2
unnamed: K_R4C7.3 (LED), R_R4C7.2
unnamed: K_R4C8.3 (LED), R_R4C8.2
unnamed: K_R4C9.3 (LED), R_R4C9.2
unnamed: K_R4C10.3 (LED), R_R4C10.2
unnamed: K_R4C11.3 (LED), R_R4C11.2
unnamed: K_R4C12.3 (LED), R_R4C12.2
unnamed: K_R4C13.3 (LED), R_R4C13.2
unnamed: K_R5C0.3 (LED), R_R5C0.2
unnamed: K_R5C1.3 (LED), R_R5C1.2
unnamed: K_R5C2.3 (LED), R_R5C2.2
unnamed: K_R5C3.3 (LED), R_R5C3.2
unnamed: K_R5C4.3 (LED), R_R5C4.2
unnamed: K_R5C6.3 (LED), R_R5C6.2
unnamed: K_R5C8.3 (LED), R_R5C8.2
unnamed: K_R5C9.3 (LED), R_R5C9.2
unnamed: K_R5C10.3 (LED), R_R5C10.2
unnamed: K_R5C11.3 (LED), R_R5C11.2
unnamed: K_R5C12.3 (LED), R_R5C12.2
unnamed: K_R5C13.3 (LED), R_R5C13.2
unnamed: Q1.1 (G), R8.1
unnamed: R1.2, SW1.2, U1.13 (~RESET)
unnamed: R2.2, U1.33 (~HWB/PE2)
unnamed: R3.1, U1.3 (D-)
unnamed: R4.1, U1.4 (D+)
unnamed: R5.2, USB1.4 (CC1)
unnamed: R6.2, USB1.10 (CC2)
SPEAKER: LS1.1, U1.12 (PB7/~RTS)
VCC: F1.2, U2.5 (VBUS), USB1.2 (VBUS), USB1.11 (VBUS)
col0: K_R0C0.1 (COL), K_R1C0.1 (COL), K_R2C0.1 (COL), K_R3C0.1 (COL), K_R4C0.1 (COL), K_R5C0.1 (COL), U1.41 (PF0)
col1: K_R1C1.1 (COL), K_R2C1.1 (COL), K_R3C1.1 (COL), K_R4C1.1 (COL), K_R5C1.1 (COL), U1.40 (PF1)
col2: K_R0C2.1 (COL), K_R1C2.1 (COL), K_R2C2.1 (COL), K_R3C2.1 (COL), K_R4C2.1 (COL), K_R5C2.1 (COL), U1.39 (PF4)
col3: K_R0C3.1 (COL), K_R1C3.1 (COL), K_R2C3.1 (COL), K_R3C3.1 (COL), K_R4C3.1 (COL), K_R5C3.1 (COL), U1.38 (PF5)
col4: K_R0C4.1 (COL), K_R1C4.1 (COL), K_R2C4.1 (COL), K_R3C4.1 (COL), K_R4C4.1 (COL), K_R5C4.1 (COL), U1.37 (PF6)
col5: K_R0C5.1 (COL), K_R1C5.1 (COL), K_R2C5.1 (COL), K_R3C5.1 (COL), K_R4C5.1 (COL), U1.36 (PF7)
col6: K_R0C6.1 (COL), K_R1C6.1 (COL), K_R2C6.1 (COL), K_R3C6.1 (COL), K_R4C6.1 (COL), K_R5C6.1 (COL), U1.32 (PC7)
col7: K_R0C7.1 (COL), K_R1C7.1 (COL), K_R2C7.1 (COL), K_R3C7.1 (COL), K_R4C7.1 (COL), U1.30 (PB6)
col8: K_R0C8.1 (COL), K_R1C8.1 (COL), K_R2C8.1 (COL), K_R3C8.1 (COL), K_R4C8.1 (COL), K_R5C8.1 (COL), U1.29 (PB5)
col9: K_R0C9.1 (COL), K_R1C9.1 (COL), K_R2C9.1 (COL), K_R3C9.1 (COL), K_R4C9.1 (COL), K_R5C9.1 (COL), U1.28 (PB4)
col10: K_R0C10.1 (COL), K_R1C10.1 (COL), K_R2C10.1 (COL), K_R3C10.1 (COL), K_R4C10.1 (COL), K_R5C10.1 (COL), U1.27 (T0/PD7)
col11: K_R0C11.1 (COL), K_R1C11.1 (COL), K_R2C11.1 (COL), K_R3C11.1 (COL), K_R4C11.1 (COL), K_R5C11.1 (COL), U1.26 (T1/PD6)
col12: K_R0C12.1 (COL), K_R1C12.1 (COL), K_R2C12.1 (COL), K_R3C12.1 (COL), K_R4C12.1 (COL), K_R5C12.1 (COL), U1.25 (ICP1/PD4)
col13: K_R0C13.1 (COL), K_R1C13.1 (COL), K_R2C13.1 (COL), K_R4C13.1 (COL), K_R5C13.1 (COL), SW2.S2, U1.22 (PD5/XCK1)
row0: D_R0C0.1 (K), D_R0C2.1 (K), D_R0C3.1 (K), D_R0C4.1 (K), D_R0C5.1 (K), D_R0C6.1 (K), D_R0C7.1 (K), D_R0C8.1 (K), D_R0C9.1 (K), D_R0C10.1 (K), D_R0C11.1 (K), D_R0C12.1 (K), D_R0C13.1 (K), U1.21 (PD3/TXD1)
row1: D_R1C0.1 (K), D_R1C1.1 (K), D_R1C2.1 (K), D_R1C3.1 (K), D_R1C4.1 (K), D_R1C5.1 (K), D_R1C6.1 (K), D_R1C7.1 (K), D_R1C8.1 (K), D_R1C9.1 (K), D_R1C10.1 (K), D_R1C11.1 (K), D_R1C12.1 (K), D_R1C13.1 (K), U1.20 (PD2/RXD1)
row2: D_R2C0.1 (K), D_R2C1.1 (K), D_R2C2.1 (K), D_R2C3.1 (K), D_R2C4.1 (K), D_R2C5.1 (K), D_R2C6.1 (K), D_R2C7.1 (K), D_R2C8.1 (K), D_R2C9.1 (K), D_R2C10.1 (K), D_R2C11.1 (K), D_R2C12.1 (K), D_R2C13.1 (K), U1.19 (PD1/INT1)
row3: D_R3C0.1 (K), D_R3C1.1 (K), D_R3C2.1 (K), D_R3C3.1 (K), D_R3C4.1 (K), D_R3C5.1 (K), D_R3C6.1 (K), D_R3C7.1 (K), D_R3C8.1 (K), D_R3C9.1 (K), D_R3C10.1 (K), D_R3C11.1 (K), D_R3C12.1 (K), D_R3C13.1 (K), U1.18 (PD0/INT0)
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

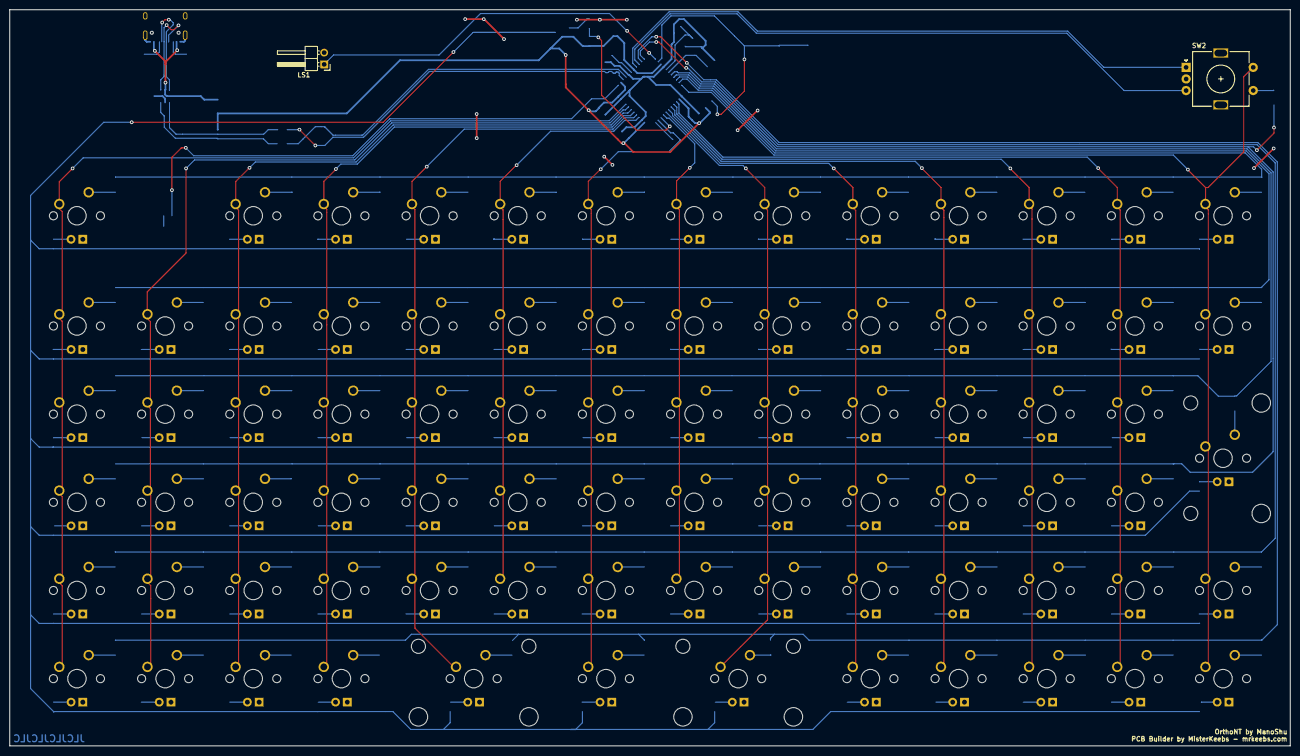
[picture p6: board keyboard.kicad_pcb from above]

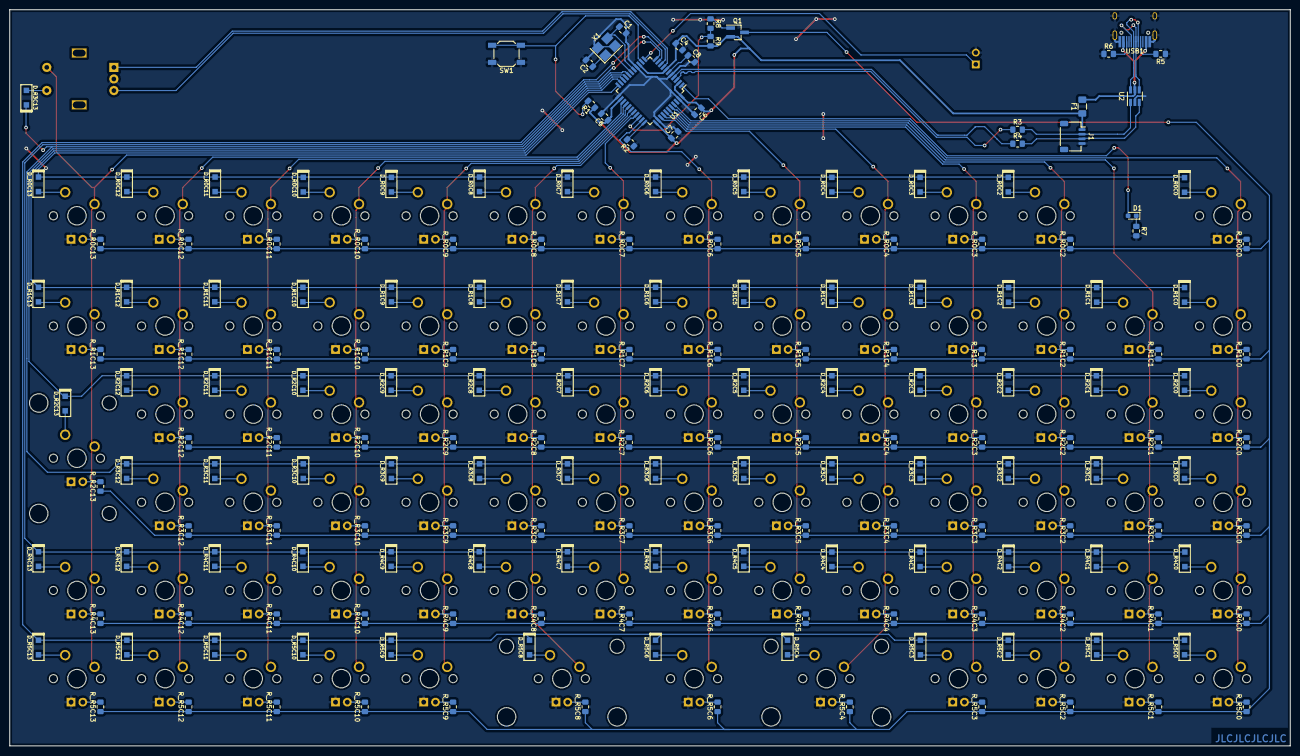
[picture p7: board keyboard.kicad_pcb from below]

Board: 2 copper layers, 276.7 x 159.1 mm, 268 parts (186 on the bottom side), 205 nets.

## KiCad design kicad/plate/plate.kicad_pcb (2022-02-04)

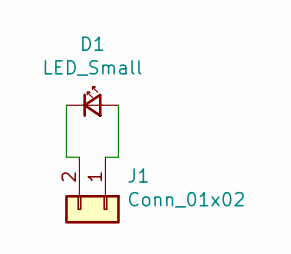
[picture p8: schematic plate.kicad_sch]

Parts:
D1: LED_Small; LED_1206_3216Metric_ReverseMount_Hole1.8x2.4mm
J1: Conn_01x02; LED_2816_7142Metric_Pad3.20x4.45mm_HandSolder

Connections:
unnamed: D1.1 (K), J1.2
unnamed: D1.2 (A), J1.1

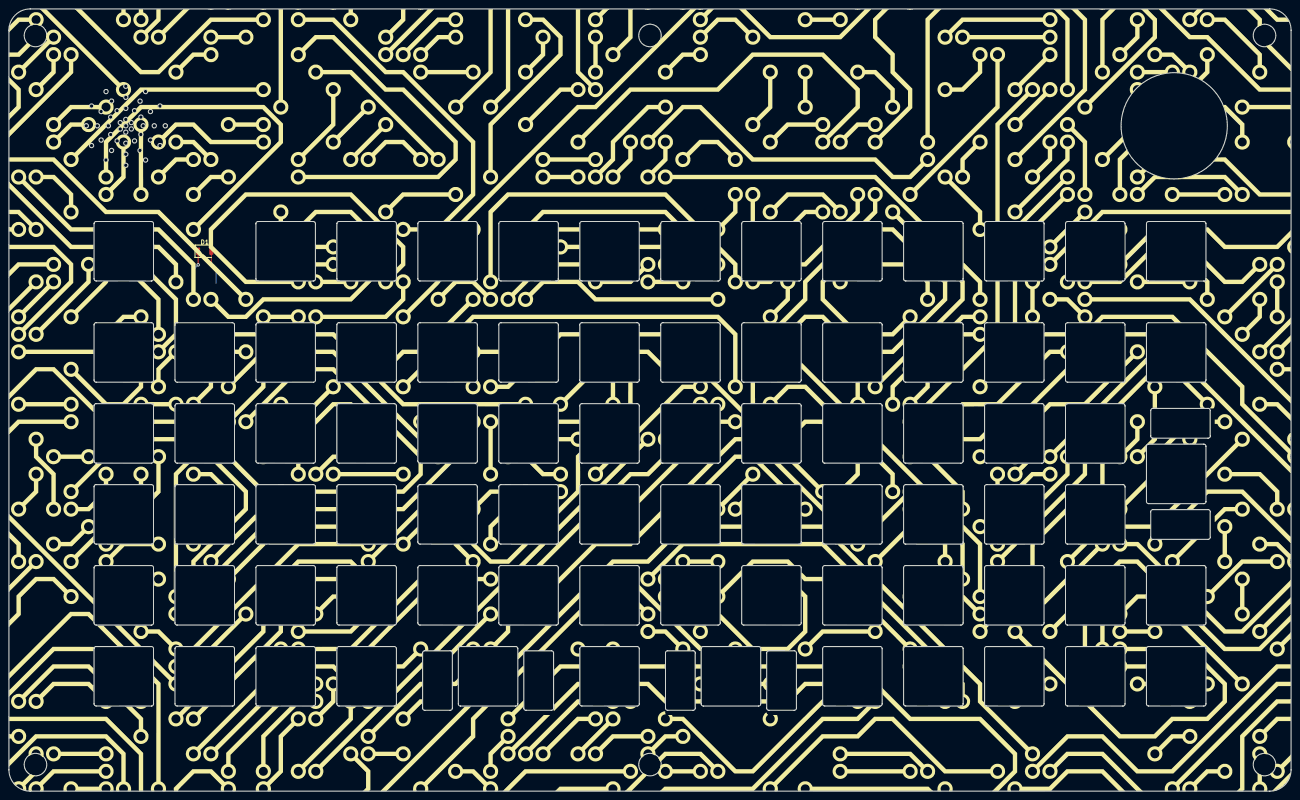
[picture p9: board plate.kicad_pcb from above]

Board: 2 copper layers, 301.7 x 184.1 mm, 3 parts (1 on the bottom side), 2 nets.

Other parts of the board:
.: .; Hole_25mm

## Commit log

2022-02-04 Main files upload
    [bom_v2.xls, bom_v2_c3only.xls, keyboard.kicad_pcb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]
2022-02-04 Fixed backlight levels and pin definition for caps lock
